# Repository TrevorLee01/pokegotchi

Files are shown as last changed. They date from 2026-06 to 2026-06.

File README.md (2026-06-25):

# Pokegotchi
tamagotchi project by Trevor Lee

ONSHAPE LINK: https://cad.onshape.com/documents/4788cfc2c41ccbd3b3bb658b/w/c8008663c56e0ba217e7b347/e/ed1d7d4fd3640974190b7d9b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

BOM INCLUDED IN THE FILES! "BOM.csv", bottom of this README, or: https://docs.google.com/spreadsheets/d/1ZSV7nk1klidvS7acBAQEKFNUl_y9adzhBfaWMznL6cg/edit?gid=0#gid=0

______________



# What is a Pokegotchi?

This pokegotchi comes with 3 whole pokemons
- Snorlax
- Solosis
- Eevee
However, Eevee comes with 5 different types of Eeveelution depending on the exact environment (a secret). Play to find out which eeveelution you end up getting!

The possible 5 includes:
- umbreon
- leafeon
- slyveon
- glaceon
- espeon

____
# Features

The unique features of this tamagotchi are
- internal clock ( to tell between day and night)
- LDR (to tell how dark it is)

(and a completely different ESP32 :D)

____
# Why did I make it?

Through my entire childhood, I've always been into some type of media related to Pokemon. Despite being it a common hobby or interest, that never discouraged me to discontinue the love I have for Pokemon. 
I think it's such a fundamental piece to my development and I want to physically manifest the fondness by utilizing the hardware opportunity given by fallout. 

____
# Pictures‼️

Here is the pcb.







Here is the CAD.



Here is the render.



____
# How It Works ╰(°▽°)╯

Turn the Pokegotchi on and select one out of three Pokémon that you want to take care of: Snorlax, Solosis, or Eevee.

The built-in real-time clock (RTC) will help you keep track of the current time, enabling the device to know whether it is day or night. In addition, the light-dependent resistor (LDR) will detect how bright the surrounding environment is and make your Pokémon respond accordingly.

Should you pick Eevee, it will evolve into one of five unique Eeveelutions, depending both on your in-game actions and some hidden environmental factors.

Use the buttons on the Pokegotchi to navigate through the menus.

____
# How to Build Your Own Pokegotchi :D

1. Print the Case: Download the .step files from the repository and use a 3D printer to print the front case and back case.

2. Solder the Components: Solder all the components to the custom PCB, including the ESP32, RTC IC, light sensor (LDR), display, buttons, and other hardware as specified in the bill of materials.

3. Place the Hardware: Install the PCB inside the printed case using 2 M3x10 screws, and then secure the top of the case using 3 M3x5 screws. Don't forget to place the battery inside its pocket, and connect it to the pinheader.

4. Upload the Firmware: Download the .ino file from the repository and flash Pokegotchi firmware onto the ESP32.

5. Get Ready for an Exciting Journey: Turn on the device, select a Pokémon, and start training your Pokegotchi!

____
# BOM

POKEGOTCHI BILL OF MATERIALS,,,,,
 Total Cost ,,,,,
 $ 44.40 ,,,,,
,,,,,
Item, Indiv Costs ,Quanities, Cost ,Links to Order,Additional Notes
ESP32-S3-WROOM-1-N16R8 MCU, $ 6.76 ,1, $ 6.76 ,https://www.digikey.com/en/products/detail/espressif-systems/ESP32-S3-WROOM-1-N16R8/16162642,
TYPE-C-31-M-12 USB-C Receptable, $ 0.19 ,5, $ 0.93 ,https://www.lcsc.com/product-detail/C165948.html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,"4 extra, MOQ 5"
XHXDZ 1207-P6.5MM Buzzer, $ 0.50 ,10, $ 5.03 ,https://www.aliexpress.us/item/3256810135642750.html,"9 extra, MOQ 10"
MCP73831T-2ATI/OT Charger, $ 0.76 ,1, $ 0.76 ,https://www.digikey.com/en/products/detail/microchip-technology/MCP73831T-2ATI-OT/964303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,
AP2112K-3.3TRG1 Voltage Regulator, $ 0.25 ,1, $ 0.25 ,https://www.digikey.com/en/products/detail/diodes-incorporated/AP2112K-3-3TRG1/4470746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,
1825910-6 Tactile Switch, $ 0.13 ,3, $ 0.39 ,https://www.digikey.com/en/products/detail/te-connectivity-alcoswitch-switches/1825910-6/1632536,
TS-104-T-A Connector, $ 1.06 ,1, $ 1.06 ,https://www.digikey.com/en/products/detail/samtec-inc/TS-104-T-A/1105490,
M20-9990246 Connector, $ 0.10 ,1, $ 0.10 ,https://www.digikey.com/en/products/detail/harwin-inc/M20-9990246/3728226?s=N4IgTCBcDaILZgAwFoCc7FgCwDYQF0BfIA,
1825910-6 Tactile Switch, $ 0.13 ,3, $ 0.39 ,https://www.digikey.com/en/products/detail/te-connectivity-alcoswitch-switches/1825910-6/1632536,
RC0805JR-075K1L Resistor, $ 0.10 ,2, $ 0.20 ,https://www.digikey.com/en/products/detail/yageo/RC0805JR-075K1L/728338,
RC0805FR-072KL Resistor, $ 0.10 ,1, $ 0.10 ,https://www.digikey.com/en/products/detail/yageo/RC0805FR-072KL/727664,
RC0805FR-0710KL Resistor, $ 0.10 ,3, $ 0.30 ,https://www.digikey.com/en/products/detail/yageo/RC0805FR-0710KL/727535,
RC0805FR-074K7L Resistor, $ 0.10 ,2, $ 0.20 ,https://www.digikey.com/en/products/detail/yageo/RC0805FR-074K7L/727929,
GL12528 LDR, $ 0.31 ,5, $ 1.56 ,https://www.lcsc.com/product-detail/C559386.html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,"4 extra, MOQ 5"
CL21B105KAFNNNE Capacitor, $ 0.10 ,1, $ 0.10 ,https://www.digikey.com/en/products/detail/samsung-electro-mechanics/CL21B105KAFNNNE/3886724,
CL21A475KAQNNNE Capacitor, $ 0.11 ,2, $ 0.22 ,https://www.digikey.com/en/products/detail/samsung-electro-mechanics/CL21A475KAQNNNE/3886902,
HS96L03W2C03 Screen, $ 1.87 ,1, $ 1.87 ,https://www.aliexpress.us/item/2251832337475453.html,
DS3231MZ+TRL Clock, $ 12.68 ,1, $ 12.68 ,https://www.digikey.com/en/products/detail/analog-devices-inc-maxim-integrated/DS3231MZ-TRL/2754408,
Battery, $ 6.20 ,1, $ 6.20 ,https://www.aliexpress.us/item/3256808658204287.html,
PCB, $ 0.40 ,5, $ 2.00 ,https://cart.jlcpcb.com/quote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,
PLA Housing, $ -   ,, $ -   ,,
M3 x 10mm Socket Cap Head Screws, $ 0.75 ,2, $ 1.50 ,https://accu-components.com/us/metric-cap-head-screws/16004-SSCF-M3-10-12-9,
M3 x 5mm Socket Cap Head Screws, $ 0.45 ,4, $ 1.80 ,https://accu-components.com/us/metric-cap-head-screws/16001-SSCF-M3-5-12-9,4 is cheaper than 3

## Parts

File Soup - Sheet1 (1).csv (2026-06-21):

SOUPSTAND BILL OF MATERIALS
Total Cost
$ 24.58
Item | Indiv Costs | Quanities | Cost | Links to Order | Additional Notes
ESP32-S3-WROOM-1-N16R8 | $ 6.76 | 1 | $ 6.76 | https://www.digikey.com/en/products/detail/espressif-systems/ESP32-S3-WROOM-1-N16R8/16162642
MAX98357AETE+T | $ 3.73 | 1 | $ 3.73 | https://www.digikey.com/en/products/detail/analog-devices-inc-maxim-integrated/MAX98357AETE-T/4936122
AP2112K-3.3TRG1 | $ 0.25 | 1 | $ 0.25 | https://www.digikey.com/en/products/detail/diodes-incorporated/AP2112K-3-3TRG1/4470746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
MCP73831T-2ATI/OT | $ 0.76 | 1 | $ 0.76 | https://www.digikey.com/en/products/detail/microchip-technology/MCP73831T-2ATI-OT/964303
TYPE-C-31-M-12 | $ 0.19 | 5 | $ 0.93 | https://www.lcsc.com/product-detail/C165948.html | 4 extra, only available in bulk
B2B-PH-K-S | $ 0.11 | 1 | $ 0.11 | https://www.digikey.com/en/products/detail/jst-sales-america-inc/B2B-PH-K-S/926611
M20-9990246 | $ 0.10 | 1 | $ 0.10 | https://www.digikey.com/en/products/detail/harwin-inc/M20-9990246/3728226?s=N4IgTCBcDaILZgAwFoCc7FgCwDYQF0BfIA
OS102011MS2QN1 | $ 0.80 | 1 | $ 0.80 | https://www.digikey.com/en/products/detail/c-k/OS102011MS2QN1/411602
1825910-6 | $ 0.13 | 3 | $ 0.39 | https://www.digikey.com/en/products/detail/te-connectivity-alcoswitch-switches/1825910-6/1632536
PTS645SM43SMTR92 LFS | $ 0.36 | 1 | $ 0.36 | https://www.digikey.com/en/products/detail/c-k/PTS645SM43SMTR92-LFS/1146840
CL21A106KQFNNNE | $ 0.10 | 4 | $ 0.40 | https://www.digikey.com/en/products/detail/samsung-electro-mechanics/CL21A106KQFNNNE/3886780
C0603C104K3RACTU | $ 0.10 | 6 | $ 0.60 | https://www.digikey.com/en/products/detail/kemet/C0603C104K3RACTU/416044
C0603C105K4RACTU | $ 0.10 | 1 | $ 0.10 | https://www.digikey.com/en/products/detail/kemet/C0603C105K4RACTU/2199788
16YXJ220MT16.3X11 | $ 0.30 | 1 | $ 0.30 | https://www.digikey.com/en/products/detail/rubycon/16YXJ220MT16-3X11/3134826
LTST-C191KFKT | $ 0.11 | 1 | $ 0.11 | https://www.digikey.com/en/products/detail/liteon/LTST-C191KFKT/386833
RC0603FR-075K1L | $ 0.10 | 2 | $ 0.20 | https://www.digikey.com/en/products/detail/yageo/RC0603FR-075K1L/727268
RC0603FR-0710KL | $ 0.10 | 2 | $ 0.20 | https://www.digikey.com/en/products/detail/yageo/RC0603FR-0710KL/726880
RR0816P-202-D | $ 0.10 | 1 | $ 0.10 | https://www.digikey.com/en/products/detail/susumu/RR0816P-202-D/432192
RC0603FR-07330RL | $ 0.10 | 1 | $ 0.10 | https://www.digikey.com/en/products/detail/yageo/RC0603FR-07330RL/727162
RMCF0603FT300K | $ 0.10 | 1 | $ 0.10 | https://www.digikey.com/en/products/detail/stackpole-electronics-inc/RMCF0603FT300K/1760826
PCB | $ 0.40 | 5 | $ 2.00 | https://cart.jlcpcb.com/quote?stencilLayer=2&stencilWidth=100&stencilLength=100&stencilCounts=5&plateType=1
PLA Housing | $ - |  | $ -
M3 x 10mm Socket Cap Head Screws | $ 0.33 | 6 | $ 1.98 | https://accu-components.com/us/metric-cap-head-screws/16004-SSCF-M3-10-12-9
M3 x 5mm Socket Cap Head Screws | $ 0.45 | 4 | $ 1.80 | https://accu-components.com/us/metric-cap-head-screws/16001-SSCF-M3-5-12-9
NS50D-0802-L82-01 Speaker | $ 2.40 | 1 | $ 2.40 | https://www.digikey.com/en/products/detail/nac-holdings-limited/NS50D-0802-L82-01/15859761

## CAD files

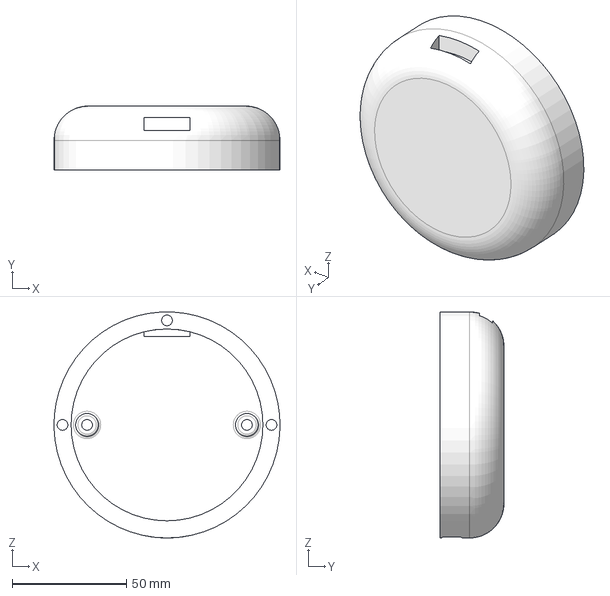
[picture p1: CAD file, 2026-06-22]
CAD/pokegotchi_top.step
99.0 x 28.0 x 98.9 mm

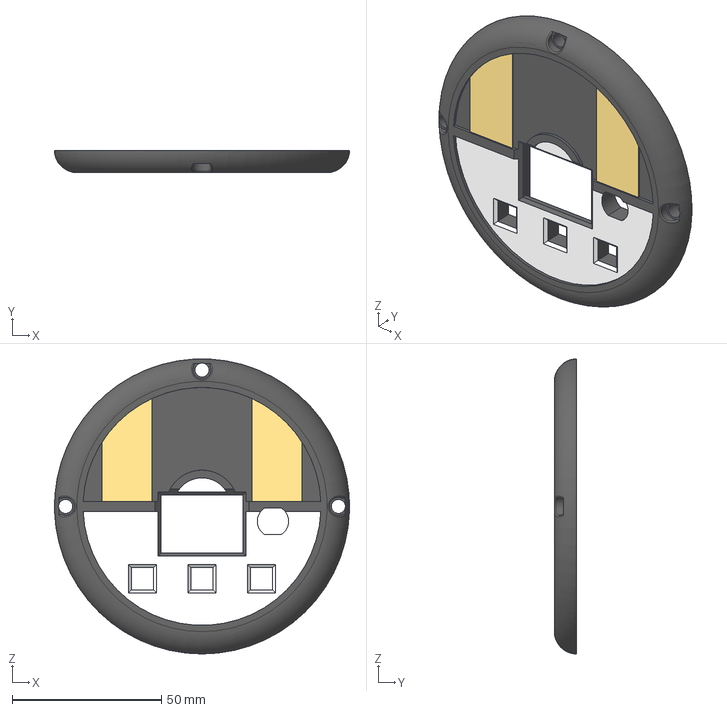
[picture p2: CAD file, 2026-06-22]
CAD/pokegotchi_bottom.step
99.0 x 7.50 x 98.9 mm

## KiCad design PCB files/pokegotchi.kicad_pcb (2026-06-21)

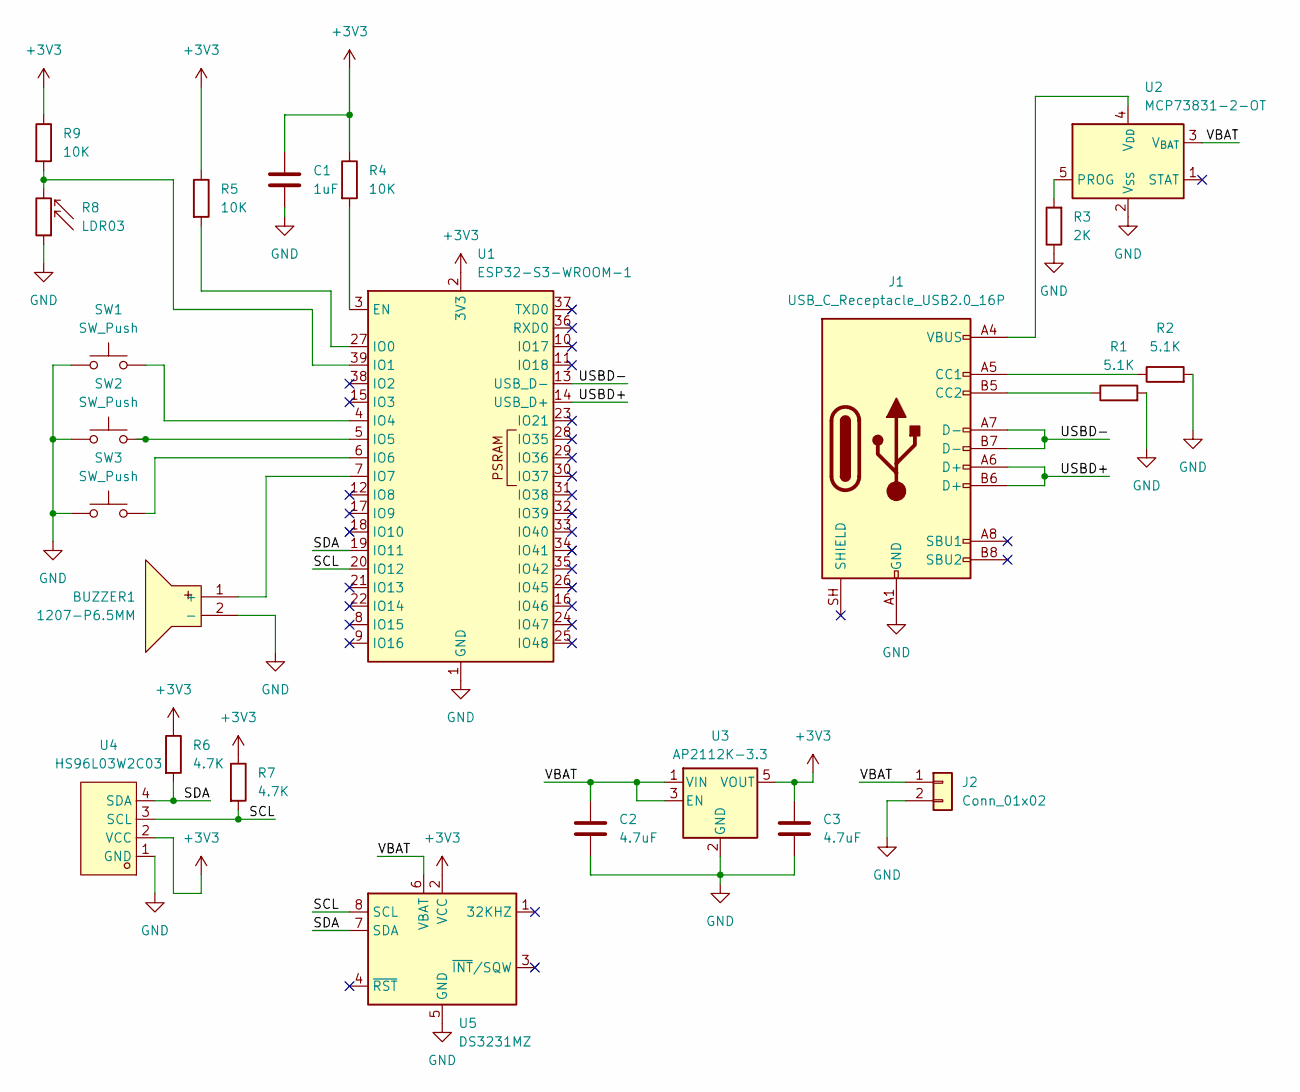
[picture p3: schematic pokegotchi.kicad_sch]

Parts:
BUZZER1: 1207-P6.5MM; BUZ-TH_BD12.5-P6.50-D1.4; MPN 1207-P6.5MM; LCSC Part C49246964
C1: 1uF; C_0805_2012Metric
C2, C3: 4.7uF; C_0805_2012Metric
J1: USB_C_Receptacle_USB2.0_16P; USB_C_Receptacle_HRO_TYPE-C-31-M-12
J2: Conn_01x02; PinHeader_1x02_P2.54mm_Vertical
R1, R2: 5.1K; R_0805_2012Metric
R3: 2K; R_0805_2012Metric
R4, R5, R9: 10K; R_0805_2012Metric
R6, R7: 4.7K; R_0805_2012Metric
R8: LDR03; R_LDR_10x8.5mm_P7.6mm_Vertical
SW1, SW2, SW3: SW_Push; SW_PUSH_6mm
U1: ESP32-S3-WROOM-1
U2: MCP73831-2-OT; SOT-23-5
U3: AP2112K-3.3; SOT-23-5
U4: HS96L03W2C03; OLED-TH_L27.8-W27.2-P2.54_C9900033791; MPN HS96L03W2C03; LCSC Part C5248080
U5: DS3231MZ; SOIC-8_3.9x4.9mm_P1.27mm

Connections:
+3V3: C1.1, C3.1, R4.1, R5.1, R6.1, R7.1, R9.1, U1.2 (3V3), U3.5 (VOUT), U4.2 (VCC), U5.2 (VCC)
/SCL: R7.2, U1.20 (IO12), U4.3 (SCL), U5.8 (SCL)
/SDA: R6.2, U1.19 (IO11), U4.4 (SDA), U5.7 (SDA)
/USBD+: J1.A6 (D+), J1.B6 (D+), U1.14 (USB_D+)
/USBD-: J1.A7 (D-), J1.B7 (D-), U1.13 (USB_D-)
/VBAT: C2.1, J2.1, U2.3 (V_{BAT}), U3.1 (VIN), U3.3 (EN), U5.6 (VBAT)
GND: BUZZER1.2 (-), C1.2, C2.2, C3.2, J1.A1 (GND), J1.A12 (GND), J1.B1 (GND), J1.B12 (GND), J2.2, R1.2, R2.2, R3.1, R8.1, SW1.1, SW2.1, SW3.1, U1.1 (GND), U1.40 (GND), U1.41 (GND), U2.2 (V_{SS}), U3.2 (GND), U4.1 (GND), U5.5 (GND)
unnamed: BUZZER1.1 (+), U1.7 (IO7)
unnamed: J1.A5 (CC1), R2.1
unnamed: J1.B5 (CC2), R1.1
unnamed: R4.2, U1.3 (EN)
unnamed: R5.2, U1.27 (IO0)
unnamed: R8.2, R9.2, U1.39 (IO1)
unnamed: SW1.2, U1.4 (IO4)
unnamed: SW2.2, U1.5 (IO5)
unnamed: SW3.2, U1.6 (IO6)
unnamed: R3.2, U2.5 (PROG)
unnamed: J1.A4 (VBUS), J1.A9 (VBUS), J1.B4 (VBUS), J1.B9 (VBUS), U2.4 (V_{DD})

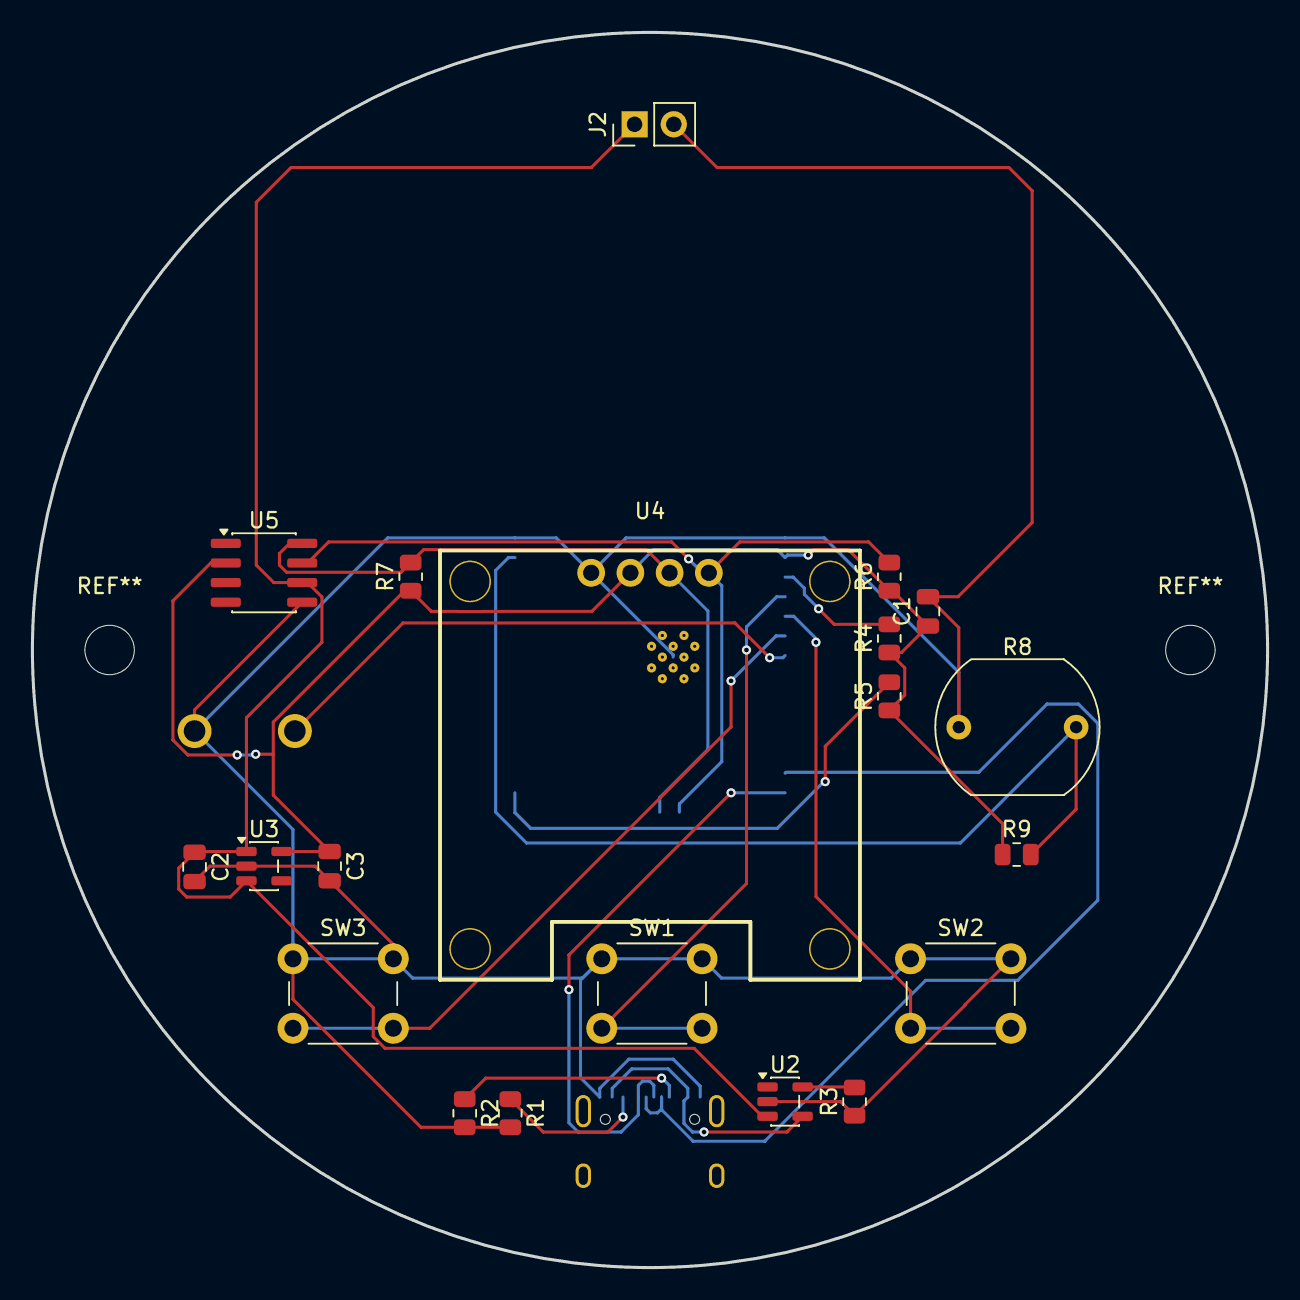
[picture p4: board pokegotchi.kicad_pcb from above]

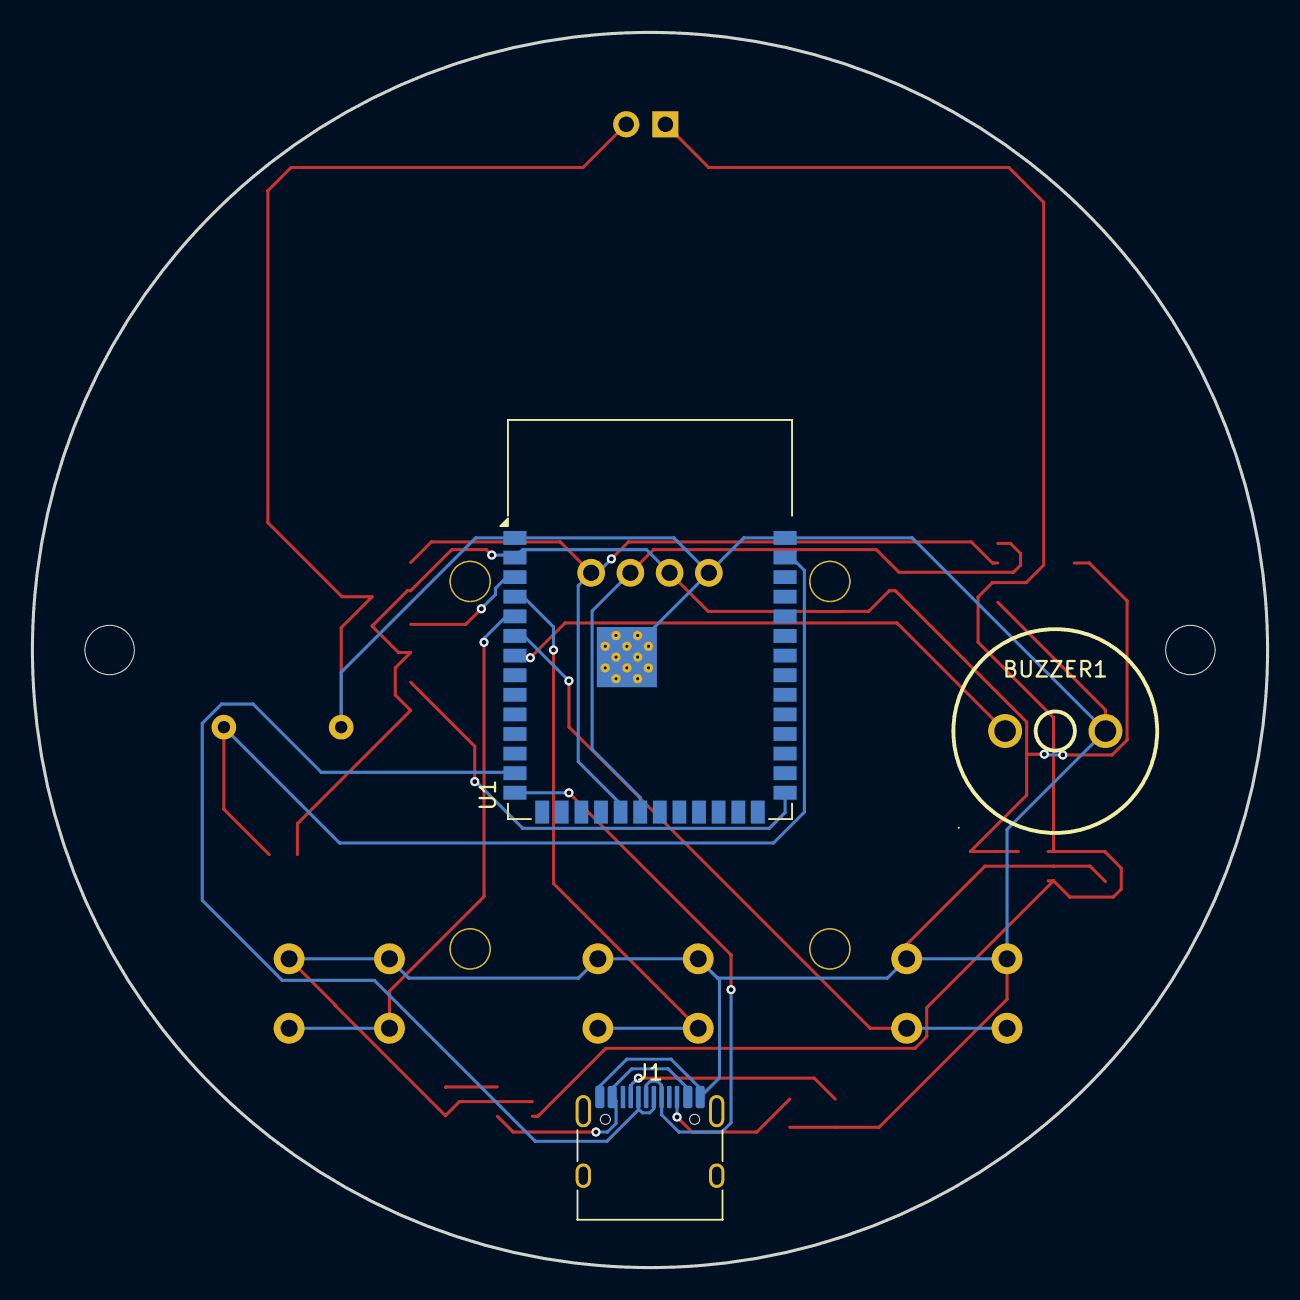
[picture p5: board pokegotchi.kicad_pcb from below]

Board: 2 copper layers, 80.0 x 80.0 mm, 23 parts (3 on the bottom side), 18 nets.

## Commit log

2026-06-21 sorted into files
    [pokegotchi.kicad_pcb, pokegotchi.kicad_sch]
2026-06-24 Rename Soup - Sheet1 (1).csv to BOM.csv
    [BOM.csv]
